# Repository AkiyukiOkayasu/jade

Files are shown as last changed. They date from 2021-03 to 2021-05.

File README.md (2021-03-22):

# jade

USB-MIDI to monome ii converter.  
Use MIDI SysEx to communicate with monome ii.  
It should be noted that this project is in its early stages.  

## Eurorack module

Image from Gyazo (https://gyazo.com/f4a5778d6a9a77acea434a3b7efffd9e)

## Firmware

### Dependencies

- PlatformIO

## Max for Live

Max for Live devices for Just Friends are available.  
Max for Live devices for ER-301 will be added soon.  
Image from Gyazo (https://gyazo.com/4216f0453e2cefc7fa490f93da770d71)

## Document

[document](https://akiyukiokayasu.github.io/jade/)

## Data format

The SysEx specification for communicating with Jade will be documented in the future.  
SysEx can only send values between 0 and 127. Therefore, 1 byte (0~255) of monome ii is divided into 2 bytes and sent.  
Like this.  

Original data (1byte):: |ABCDEFGH|  
Divide data (2bytes):: |0000ABCD| |0000EFGH|  

## LICENSE  

MIT

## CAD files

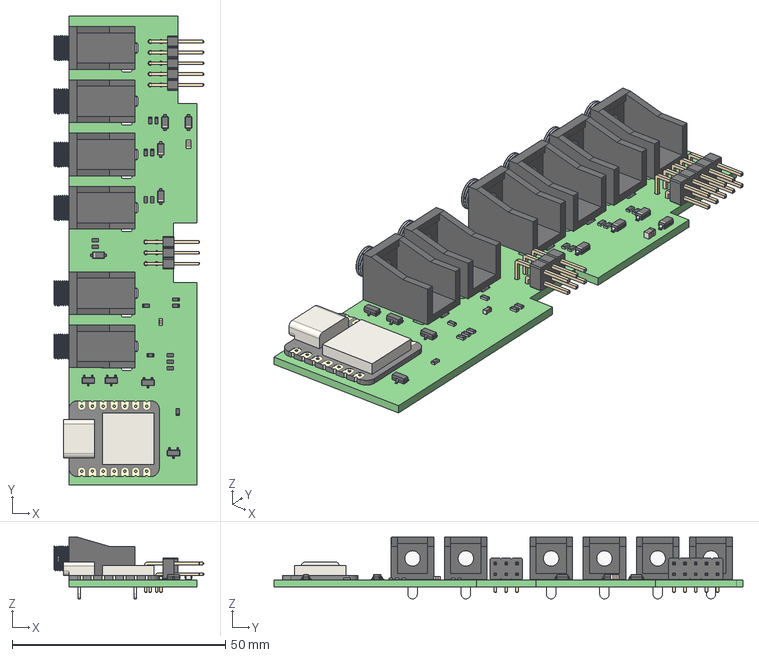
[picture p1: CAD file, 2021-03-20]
Hardware/3d/jade_hardware.step
35.1 x 110.0 x 14.5 mm

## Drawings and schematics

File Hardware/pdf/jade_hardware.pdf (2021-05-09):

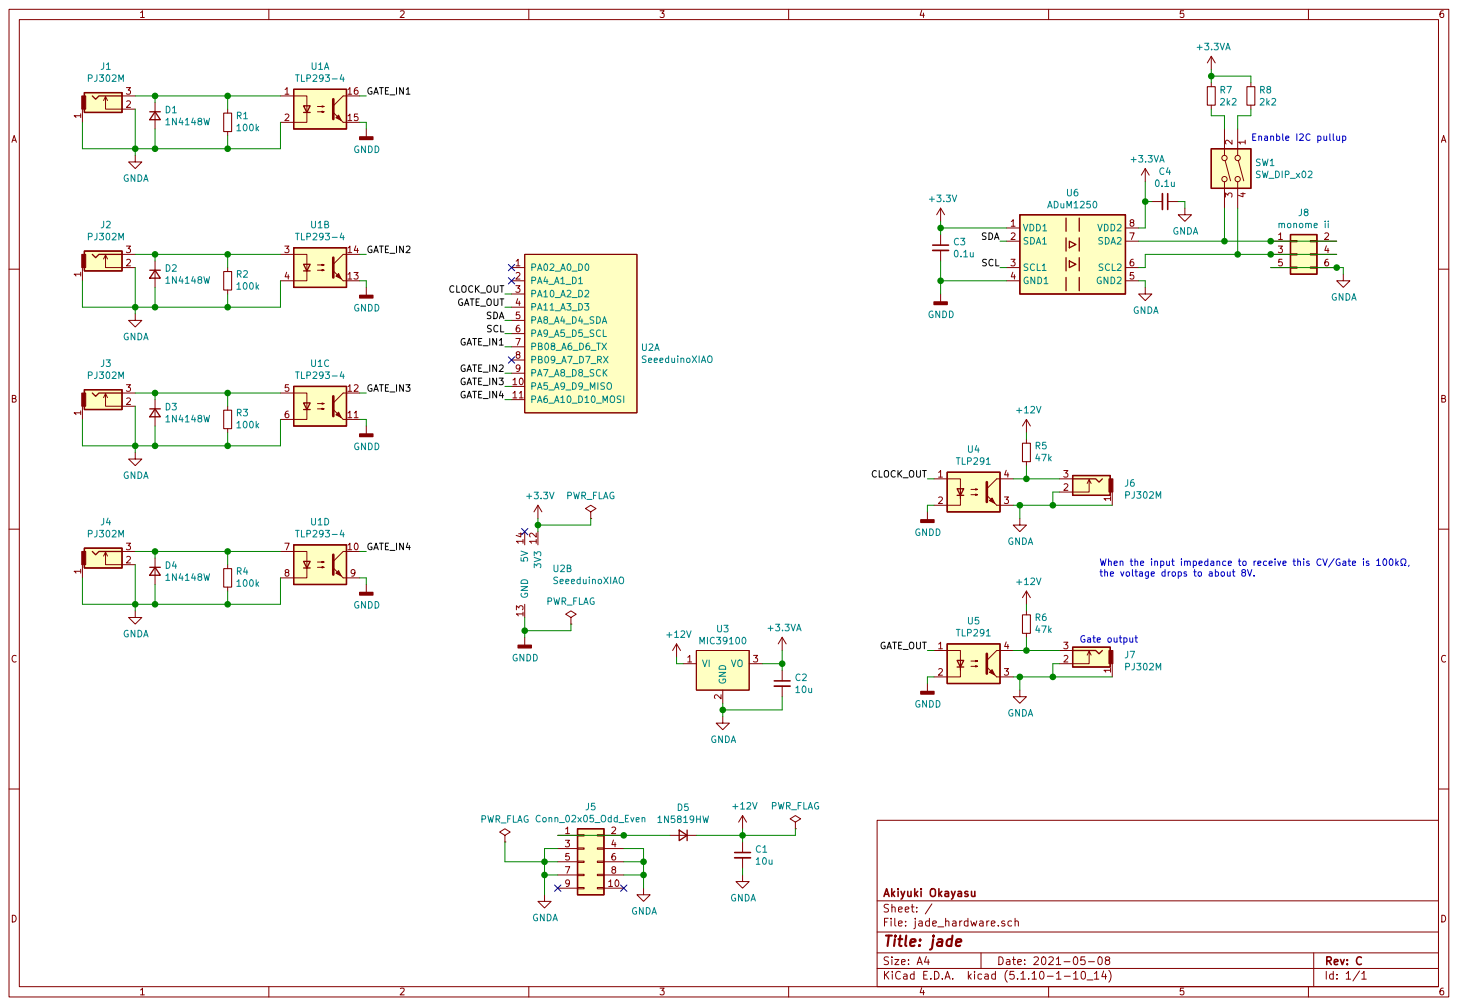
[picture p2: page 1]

When the input impedance to receive this CV/Gate is 100k,
the voltage drops to about 8V.

File: jade_hardware.sch Sheet: / Akiyuki Okayasu

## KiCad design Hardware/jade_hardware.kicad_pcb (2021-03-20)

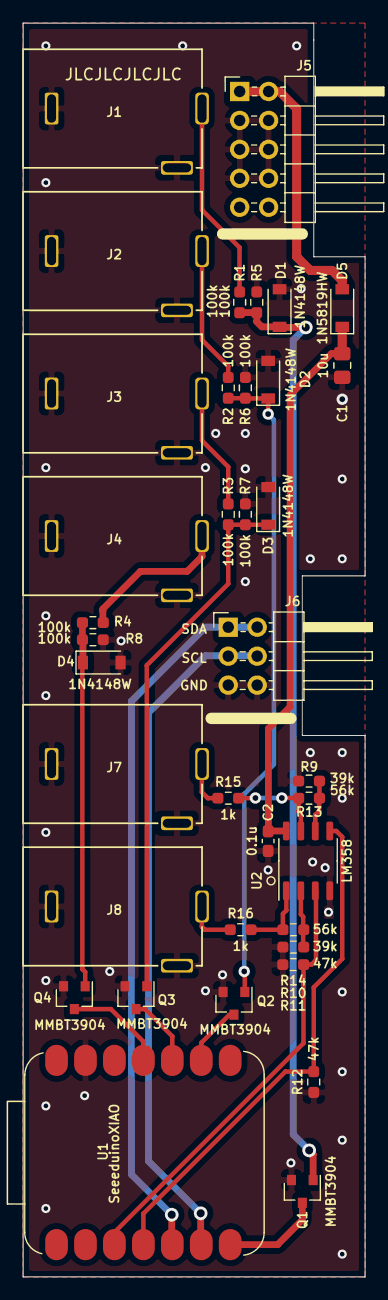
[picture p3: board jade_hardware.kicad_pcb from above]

Board: 2 copper layers, 30.0 x 110.0 mm, 37 parts (0 on the bottom side), 25 nets.

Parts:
C1: 10u; C_0805_2012Metric_Pad1.18x1.45mm_HandSolder
C2: 0.1u; C_0603_1608Metric_Pad1.08x0.95mm_HandSolder
D1, D2, D3, D4: 1N4148W; D_SOD-123
D5: 1N5819HW; D_SOD-123
J1, J2, J3, J4, J7, J8: PJ302M
J5: Conn_02x05_Odd_Even; PinHeader_2x05_P2.54mm_Horizontal
J6: Conn_02x03_Odd_Even; PinHeader_2x03_P2.54mm_Horizontal
Q1, Q2, Q3, Q4: MMBT3904; SOT-23
R1, R2, R3, R4, R5, R6, R7, R8: 100k; R_0603_1608Metric_Pad0.98x0.95mm_HandSolder
R9, R10: 39k; R_0603_1608Metric_Pad0.98x0.95mm_HandSolder
R11, R12: 47k; R_0603_1608Metric_Pad0.98x0.95mm_HandSolder
R13, R14: 56k; R_0603_1608Metric_Pad0.98x0.95mm_HandSolder
R15, R16: 1k; R_0603_1608Metric_Pad0.98x0.95mm_HandSolder
U1: SeeeduinoXIAO; Seeeduino_XIAO_NonBottomPad
U2: LM358; SOP-8_3.9x4.9mm_P1.27mm

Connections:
+12V: C1.1, C2.1, D5.1, U2.8
/CLOCK_OUT: R11.2, U1.3, U2.3
/GATE_IN1: Q1.3, U1.7
/GATE_IN2: Q2.3, U1.9
/GATE_IN3: Q3.3, U1.10
/GATE_IN4: Q4.3, U1.11
/GATE_OUT: R12.2, U1.4, U2.5
/SCL: J6.3, J6.4, U1.6
/SDA: J6.1, J6.2, U1.5
GND: C1.2, C2.2, D1.2, D2.2, D3.2, D4.2, J1.1, J1.2, J2.1, J2.2, J3.1, J3.2, J4.1, J4.2, J5.3, J5.4, J5.5, J5.6, J5.7, J5.8, J6.5, J6.6, J7.1, J7.2, J8.1, J8.2, Q1.2, Q2.2, Q3.2, Q4.2, R5.1, R6.1, R7.1, R8.1, R9.2, R10.2, R11.1, R12.1, U1.13, U2.4
unnamed: D1.1, Q1.1, R1.1, R5.2
unnamed: D2.1, Q2.1, R2.1, R6.2
unnamed: D3.1, Q3.1, R3.1, R7.2
unnamed: D4.1, Q4.1, R4.1, R8.2
unnamed: D5.2, J5.1, J5.2
unnamed: J1.3, R1.2
unnamed: J2.3, R2.2
unnamed: J3.3, R3.2
unnamed: J4.3, R4.2
unnamed: J7.3, R15.1
unnamed: J8.3, R16.1
unnamed: R10.1, R14.2, U2.2
unnamed: R13.1, R15.2, U2.7
unnamed: R9.1, R13.2, U2.6
unnamed: R14.1, R16.2, U2.1

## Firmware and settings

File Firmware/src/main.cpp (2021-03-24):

/** jade main
    @file main.cpp
    @author Akiyuki Okayasu (akiyuki.okayasu@gmail.com)
    @copyright Copyright (c) 2021 - Akiyuki Okayasu
*/

#include "MIDI/MIDIGenerator.hpp"
#include "MIDI/MIDIParser.hpp"
#include "MIDIUSB.h"
#include "pin.hpp"

#include <Arduino.h>
#include <Wire.h> // I2C
#include <array>
#include <atomic>

UsbMidiParser midiParser;

constexpr uint8_t NUM_GATE_INPUTS = 4;

enum class GateInputState : uint8_t
{
    Low = 0, ///< Nothing to do
    Rise,    ///< MIDI note on
    High,    ///< Nothing to do
    Fall     ///< MIDI note off
};

std::array<std::atomic<GateInputState>, NUM_GATE_INPUTS> gateInputStates {};

//============== Util ===========================================================================
/** [0, 127]の範囲の2つのuint8を[0, 255]とする.
    @param msb [0, 127]
    @param lsb [0, 127]
    @return constexpr uint8_t [0, 255]
    @note SysExの仕組み上128以上の数は送信できないのでI2Cの1byteを2byteに分割して送信している
*/
constexpr uint8_t mergeBytes (const uint8_t msb, const uint8_t lsb)
{
    return (msb << 4) | (lsb & 0x0F);
}

//=============== MIDI callback =========================================================================
/** SysExのコールバック関数.
    @param sysEx 受信したデータ配列 (SysEx開始, 終了の0xF0と0xF7を除く)
    @param size データ配列の長さ    
*/
void sysExCallback (const uint8_t sysEx[], const uint8_t size)
{
    // jadeに送られるSysExのバイト分割をするので必ず偶数サイズになる
    if (size % 2 != 0)
        return;

    // 最初の2バイトはUniversalSysEx非営利, JadeのSysExデバイスIDとなる
    if (sysEx[0] == SysEx::ManufacturerID::NON_COMMERCIAL && sysEx[1] == SysEx::DeviceID::JADE)
    {
        const uint8_t addr = mergeBytes (sysEx[2], sysEx[3]);
        Wire.beginTransmission (addr);
        for (uint_fast8_t i = 4; i < size; i += 2)
        {
            const uint8_t data = mergeBytes (sysEx[i], sysEx[i + 1]);
            Wire.write (data);
        }

        /* I2C送信結果
        0 : Success
        1 : Data too long
        2 : NACK on transmit of address
        3 : NACK on transmit of data
        4 : Other error
        */
        uint8_t res = Wire.endTransmission();
    }
}

/** Note on callback
    @param note input MIDI note
    @see MIDI::Note
*/
void noteOnCallback (MIDI::Note note)
{
    digitalWrite (pin::GATE_OUT, HIGH);
}

/** Note off callback
    @param note input MIDI note
    @see MIDI::Note
*/
void noteOffCallback (MIDI::Note note)
{
    digitalWrite (pin::GATE_OUT, LOW);
}

/** Control change callback
    @param cc input MIDI control change
    @see MIDI::ControlChange
*/
void controlChangeCallback (MIDI::ControlChange cc)
{
    if (cc.value > 0)
    {
        digitalWrite (pin::LED, LOW);
    }
    else
    {
        digitalWrite (pin::LED, HIGH);
    }
}

std::atomic<uint8_t> MidiClockCounter { 0 };
constexpr uint8_t MaxMidiClockCounter { 6 }; //16分音符間隔のクロック。MIDIクロックが4分音符あたりに24クロックなので、6クロック分が16分音符。

/** SystemRealtime callback    
    @param byte SystemRealtime is 1byte message.
    @see SystemRealtime
    @todo 再生再開時のMidiClockCounterの処遇の検討。クロックの頭が揃わない問題がある。
*/
void systemRealtimeCallback (uint8_t byte)
{
    switch (byte)
    {
        case SystemRealtime::TIMING_CLOCK:
            if (MidiClockCounter == 0)
                digitalWrite (pin::CLOCK_OUT, 1);

            if (MidiClockCounter == 1)
                digitalWrite (pin::CLOCK_OUT, 0);

            MidiClockCounter = MidiClockCounter + 1;
            if (MidiClockCounter == MaxMidiClockCounter)
                MidiClockCounter = 0;

            break;
        case SystemRealtime::START:
            MidiClockCounter = 0;
            break;
        case SystemRealtime::CONTINUE:
            // TODO 再生再開時のMidiClockCounterの処遇の検討。クロックの頭が揃わない問題がある。
            break;
        case SystemRealtime::STOP:
            break;
        default:
            break;
    }
}

//=============== Gate input callback =========================================================================
/** Set current gate state to gateInputStates.
    @param gate Gate input state True: high, False: low
    @param index gateInputStates's index [0, 3]
*/
inline void updateGateInState (bool gate, uint8_t index)
{
    if (gate == false && gateInputStates[index] == GateInputState::Low)
    {
        gateInputStates[index] = GateInputState::Rise;
    }
    else if (gate == true && gateInputStates[index] == GateInputState::High)
    {
        gateInputStates[index] = GateInputState::Fall;
    }
}

void gate1Changed()
{
    updateGateInState (digitalRead (pin::GATE_IN1), 0);
}

void gate2Changed()
{
    updateGateInState (digitalRead (pin::GATE_IN2), 1);
}

void gate3Changed()
{
    updateGateInState (digitalRead (pin::GATE_IN3), 2);
}

void gate4Changed()
{
    updateGateInState (digitalRead (pin::GATE_IN4), 3);
}

//==================================================================================================
void setup()
{
    // MIDI callback
    midiParser.onNoteOn = noteOnCallback;
    midiParser.onNoteOff = noteOffCallback;
    midiParser.onControlChange = controlChangeCallback;
    midiParser.onSysEx = sysExCallback;
    midiParser.onSystemRealtime = systemRealtimeCallback;

    // I2Cピンの内部プルアップ
    pinMode (pin::I2C_SCL, INPUT_PULLUP);
    pinMode (pin::I2C_SDA, INPUT_PULLUP);
    Wire.begin(); // I2C setup

    // GPIO
    pinMode (pin::CLOCK_OUT, OUTPUT);
    digitalWrite (pin::CLOCK_OUT, LOW);
    pinMode (pin::GATE_OUT, OUTPUT);
    digitalWrite (pin::GATE_OUT, LOW);
    pinMode (pin::LED, OUTPUT);
    digitalWrite (pin::LED, HIGH);

    // GATE in
    pinMode (pin::GATE_IN1, INPUT_PULLUP);
    pinMode (pin::GATE_IN2, INPUT_PULLUP);
    pinMode (pin::GATE_IN3, INPUT_PULLUP);
    pinMode (pin::GATE_IN4, INPUT_PULLUP);
    attachInterrupt (pin::GATE_IN1, gate1Changed, CHANGE);
    attachInterrupt (pin::GATE_IN2, gate2Changed, CHANGE);
    attachInterrupt (pin::GATE_IN3, gate3Changed, CHANGE);
    attachInterrupt (pin::GATE_IN4, gate4Changed, CHANGE);

    delay (1000);
}

void loop()
{
    midiEventPacket_t rx;
    do
    {
        rx = MidiUSB.read();
        midiParser.parse (rx);
    } while (rx.header != 0);

    for (uint8_t i = 0; i < gateInputStates.size(); ++i)
    {
        if (gateInputStates[i] == GateInputState::Rise)
        {
            // MIDI note on
            MidiUSB.sendMIDI (makeNoteOn (60, 127, i));
            gateInputStates[i] = GateInputState::High;
        }
        else if (gateInputStates[i] == GateInputState::Fall)
        {
            // MIDI note off
            MidiUSB.sendMIDI (makeNoteOff (60, i));
            gateInputStates[i] = GateInputState::Low;
        }
    }
    MidiUSB.flush();

    delayMicroseconds (50);
}

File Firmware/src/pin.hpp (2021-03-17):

/** 
    Constants about Seeeduino XAIO GPIO.
    @file pin.hpp
    @author Akiyuki Okayasu (akiyuki.okayasu@gmail.com)
    @copyright Copyright (c) 2021 - Akiyuki Okayasu    
*/

#pragma once

namespace pin
{
constexpr uint8_t LED = 13;
constexpr uint8_t I2C_SDA = 4;
constexpr uint8_t I2C_SCL = 5;
constexpr uint8_t CLOCK_OUT = 3; ///< D3
constexpr uint8_t GATE_OUT = 2;  ///< D2
constexpr uint8_t GATE_IN1 = 6;  ///< D6
constexpr uint8_t GATE_IN2 = 8;  ///< D8
constexpr uint8_t GATE_IN3 = 9;  ///< D9
constexpr uint8_t GATE_IN4 = 10; ///< D10
} // namespace pin

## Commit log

2020-11-11 Add: pin定数を記述するヘッダーpin.hppを追加
2020-11-11 Update: LチカをMIDIParseクラスでやってみた
2020-11-12 変数名微調整
2020-11-12 Add: MIDI用コールバック関数の抽象クラス
2020-11-12 Update: noteON/OFFのコールバック関数化
2020-11-12 Add: MIDI CCのコールバック追加
2020-11-13 Remove: 使わなくなったコードを削除
2020-11-27 iiの定数ヘッダー
2020-11-27 MaxからのSerialでJF動いた
2020-11-27 コード整理
2020-11-27 Maxパッチ追加
2020-11-27 pin定数の名前空間追加
2020-11-27 pin定数の名前空間追加に伴った変更
2020-11-27 I2Cピンの内部プルアップ
2020-11-29 ボーレード更新
2020-12-01 uint8 2つを合成する関数を追加
2020-12-01 Add: SysEx都合のバイト分割をしたバージョン
2020-12-01 不要なコメントを削除
2020-12-01 バイト分割版でもJF Voxできた
2020-12-01 JF voxのパッチ
2020-12-03 Update: メインループの遅延を50usに短縮
2020-12-03 Remove: jfSetup(), iiJF()を削除
2020-12-03 Remove: プリントを削除
2020-12-03 Update: Maxパッチ更新
2021-02-11 monome iiの定数を明確化
2021-02-11 Seeeduino XAIOのGPIO定数
2021-02-11 MIDIの定数
2021-02-11 MIDIパーサーをstd::functionなどを使って綺麗にした
2021-02-11 前回のコミットの追加忘れ
2021-02-11 main.cppにこれまでの変更を適用
2021-02-11 Remove: 不使用のincludeを削除
2021-02-11 一部のuint_fast8_tをuint8に置き換え
2021-02-11 MIDI定数の追加
2021-02-11 MIDIParserのリファクタリング
2021-02-11 MIDIParserの更新に合わせてmainを対応
2021-02-12 Fix: pinModeでOUTPUTを指定するはずがHIGHと書いてしまっていたのを修正
    どちらも1なので問題なく動いてしまっていた
2021-02-12 Add: タイマーコールバックでクロック出力機能追加
2021-02-12 D3ピン定数を追加
2021-02-12 TC3とTC4で2系統のクロックを出力
2021-02-12 TODO タイマーのカウンターサイズを16bitに下げた
2021-02-23 Update: pin constants name
2021-02-23 remove: Timer4
2021-02-23 Update: 32bit hardware timer
2021-02-24 Add SysEx device id for jade
2021-03-02 32bitタイマーでクロック出力できた
2021-03-02 MIDIノート入力ででGATE ON/OFF
2021-03-02 TODOコメント追加
2021-03-02 GPIO定数を追加（GATE_IN 1~5）
2021-03-02 コメントの集成
2021-03-02 pin5と7の割り込みは同時に使えないので、pin7を使うのをやめ、GATE_INは4個に減らした
2021-03-02 Serialのボーレートを115200に指定
2021-03-02 GateInput機能実装完了
2021-03-03 いらないプリント消した
2021-03-08 Add a Hardware folder
    [GateIn.sch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]
2021-03-08 Add a Panel folder
    [jade_panel.kicad_pcb]
2021-03-08 Remove gerber files
    [jade_hardware-B_Cu.gbr, jade_hardware-B_Mask.gbr, jade_hardware-B_Paste.gbr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]
2021-03-08 jadeのSysEx受信部分を新しいjade用SysExフォーマットに合わせた
2021-03-08 サブパッチの名称変更 SysExTerminate→jadeSysExTerminator.maxpat
    jade用のサブコマンドが増えてSysExTerminateでは実態に則さなくなったため
2021-03-08 jade_JF_modeをスリムにし、Info Viewのコメントを記載した
2021-03-08 サブパッチの更新に追従した
2021-03-08 JF Run用のM4Lできた
2021-03-09 初期値調整
2021-03-09 JF VTR微調整
2021-03-09 Add some monome ii device ID
2021-03-15 JadeのGate入力の数（4）をコンパイル時定数として定義
2021-03-15 MIDIコールバック関数をラムダから明示的な関数に変更
2021-03-15 USB-MIDIパケット生成用関数群を定義
2021-03-15 Gate入力のハンドラを追加
2021-03-15 GPIOのattacInteruptをFALLINGからCHANGEに変更
2021-03-15 Gate入力に応じてUSB-MIDIのnote on/offする機能を追加
2021-03-16 JF tick v0.5.2 同期の感覚を1n~16nで選択可能にした
2021-03-16 見た目の調整 6.5pxグリッドに変更
2021-03-16 JF tick: LiveのBPMを下げた際に、同期に関係なくトリガーされてしまう問題を修正
2021-03-16 M4L全デバイスの見た目の調整
2021-03-17 Gate入力の状態遷移が行われない問題を修正
2021-03-17 Clock outとGate outのGPIOが入れ替わってたのを修正
2021-03-17 SysExの長さのassertが間違ってたのを修正
2021-03-17 JF noteとJF modeの動作確認OK
2021-03-17 デバッグ用のprint削除
2021-03-17 MIDI channel messageの定数を追加
2021-03-17 MIDI note on/offの1バイト目が間違ってたのを修正
2021-03-17 MidiUSB.flush()の位置を移動
2021-03-18 print消した
2021-03-18 jade_Clock AbletonのBPMと同じ値をjadeのClockに送信する
2021-03-19 MIDI noteのみ出力せず、その他のMIDIは素通しするやつ
2021-03-19 JF_noteとJF_voxのmidiparseの仕様？でMIDI noteが出力されなくなる問題を回避
2021-03-19 SystemRealtime用の定数を追加
2021-03-19 MIDI clockを受け、4分音符間隔でclockを出力する機能追加
2021-03-19 TODO追加 MIDIクロックのカウンター
2021-03-19 MIDIクロックでクロック出力はできたので、ハードウェアタイマーのライブラリを削除
2021-03-20 Eurorack main board Rev.B
    [jade_hardware.kicad_pcb, jade_hardware.sch, jade_hardware.step]
2021-03-20 PCB Panel for Rev.B
    [jade_panel.kicad_pcb, jade_panel.sch]
2021-03-22 SysEx出力するM4LデバイスをAbleton Live 10.0.0以降にのみ対応とした
    Live10以前はM4LからのSysEx出力はサポートされていないため。
2021-03-22 jade_JF_runのfreeze忘れ
2021-03-23 最近のJF note, voxの変更によってSysExが出力されなくなっていた問題を修正
2021-03-24 ER-301のiiコマンド定数を追加
2021-03-24 Clock出力を16分音符間隔に変更
2021-05-09 Schematic Rev.C
    [jade_hardware.sch]
2021-08-03 リファクタ
2022-03-03 KiCad6に移行
    [GateIn.sch, jade_hardware.kicad_sch, jade_hardware.sch]
2026-04-13 保存し直し
2026-04-13 feat: 起動時にJFのmodeを送信する
